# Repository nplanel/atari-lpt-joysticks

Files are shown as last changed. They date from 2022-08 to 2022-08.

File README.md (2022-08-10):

# Atari LPT/parallel port joysticks extension
## printer port 4 Players adaptor



4 Player games:

* Frogs https://www.hd-videofilm.com/frogs/
* Gauntlet II
* Leathernecks
* ST Soccer
* ... ?

## Pinout

|  DB 25 |  Joystick 3 |  Joystick 4 |
|---|:---:|---:|
| 1 | | 6 |
| 2 | | 1 |
| 3 | | 2 |
| 4 | | 3 |
| 5 | | 4 |
| 6 |  1  | |
| 7 |  2  | |
| 8 |  3  | |
| 9 |  4  | |
| 11 |  6  | |
| 24  (GND) | 8 | |
| 25  (GND) | | 8 |

## Software

C library and GFA binding are available here : https://github.com/bganne/libjoy.git

### made @ ADN 2022 https://demozoo.org/parties/4452/

# Have fun /I\\ :)

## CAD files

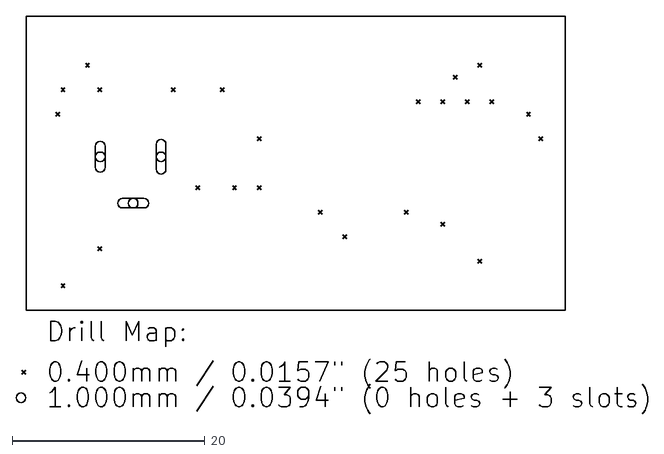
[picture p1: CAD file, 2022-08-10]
gerber/atari-lpt-joysticks-PTH-drl_map.dxf
65.5 x 41.2

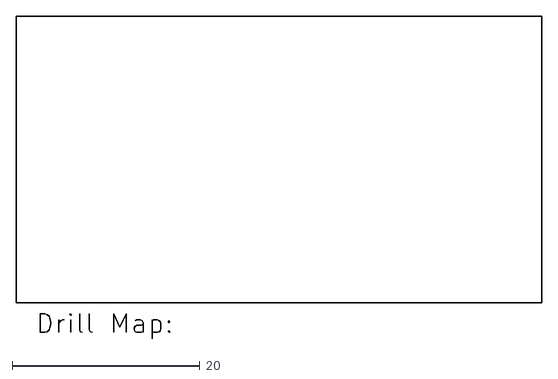
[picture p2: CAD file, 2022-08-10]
gerber/atari-lpt-joysticks-NPTH-drl_map.dxf
55.9 x 34.3

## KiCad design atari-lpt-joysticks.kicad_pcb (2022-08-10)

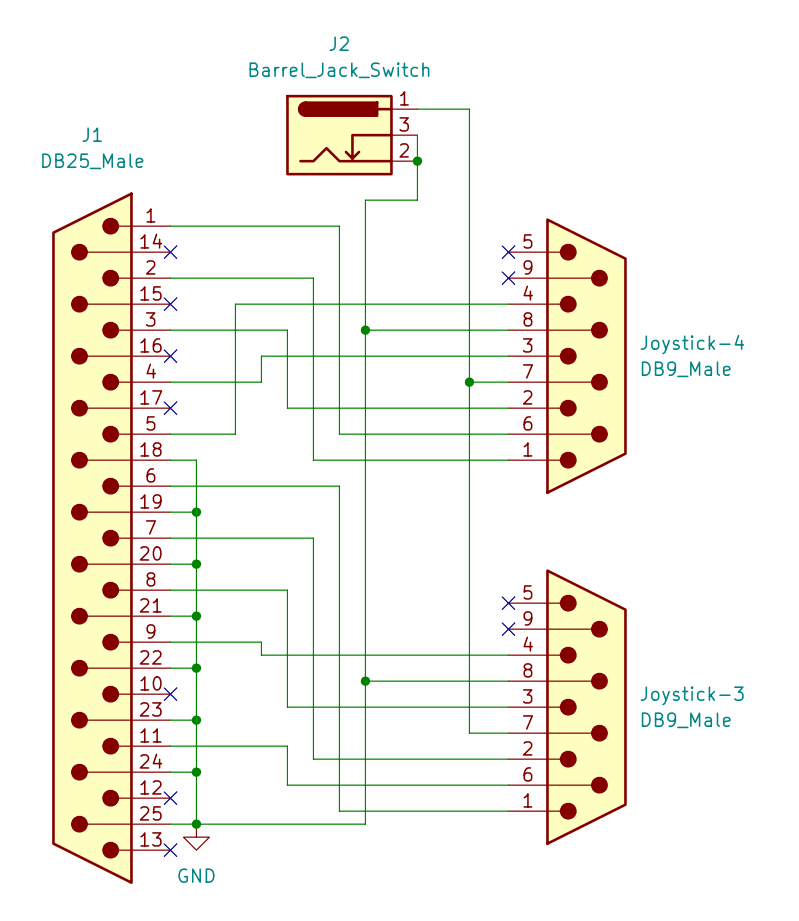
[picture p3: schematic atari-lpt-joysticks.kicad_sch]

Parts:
J1: DB25_Male; DSUB-25_Male_EdgeMount_P2.77mm
J2: Barrel_Jack_Switch; BarrelJack_GCT_DCJ200-10-A_Horizontal
Joystick-3, Joystick-4: DB9_Male; DSUB-9_Male_EdgeMount_P2.77mm

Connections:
GND: J1.18, J1.19, J1.20, J1.21, J1.22, J1.23, J1.24, J1.25, J2.2, J2.3, Joystick-3.8, Joystick-4.8
unnamed: J1.1, Joystick-4.6
unnamed: J1.2, Joystick-4.1
unnamed: J1.3, Joystick-4.2
unnamed: J1.4, Joystick-4.3
unnamed: J1.5, Joystick-4.4
unnamed: J1.6, Joystick-3.1
unnamed: J1.7, Joystick-3.2
unnamed: J1.8, Joystick-3.3
unnamed: J1.9, Joystick-3.4
unnamed: J1.11, Joystick-3.6
unnamed: J2.1, Joystick-3.7, Joystick-4.7

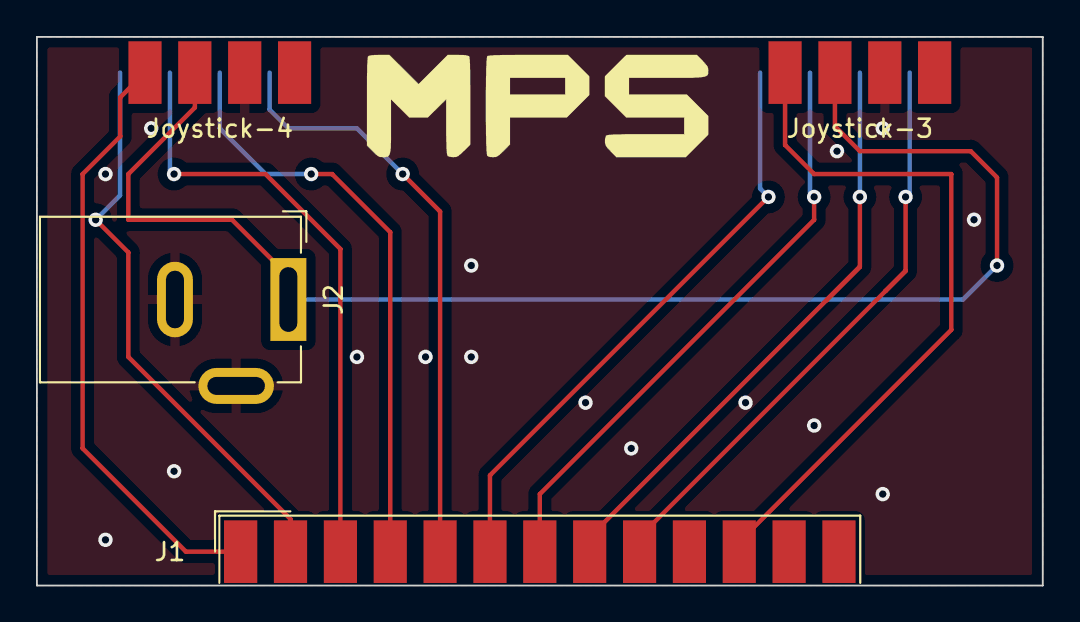
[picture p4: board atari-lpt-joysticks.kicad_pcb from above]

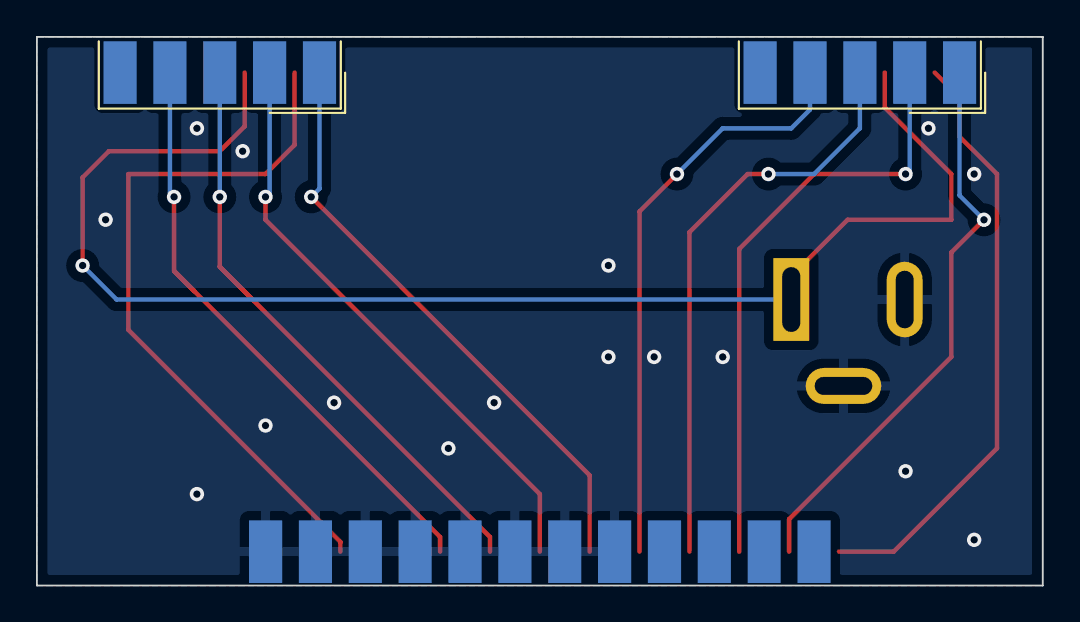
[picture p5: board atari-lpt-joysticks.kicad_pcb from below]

Board: 2 copper layers, 55.9 x 30.5 mm, 4 parts (2 on the bottom side), 12 nets.

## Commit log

2022-08-01 Atari ST LPT/parallel port joysticks extension
    [atari-lpt-joysticks-B_Cu.gbl, atari-lpt-joysticks-B_Mask.gbs, atari-lpt-joysticks-B_Paste.gbp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]
2022-08-01 Add adapter PCB pic
2022-08-10 swap joystick 3 and 4
    hardware description are not correct :
    * http://atari4ever.free.fr/hardware/zip/4joy_ada.zip
    * https://www.atari-forum.com/viewtopic.php?p=318615#p318615
    Gauntlet 2 and Leatherneck game use this pinout
    Discussion : https://github.com/hatari/hatari/pull/22
    [atari-lpt-joysticks-B_Cu.gbl, atari-lpt-joysticks-B_Mask.gbs, atari-lpt-joysticks-B_Paste.gbp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]
